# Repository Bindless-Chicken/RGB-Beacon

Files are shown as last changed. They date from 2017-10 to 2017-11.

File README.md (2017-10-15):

<h1 align=center>
   
    <br>
    RGB Beacon
    <br>
</h1>

The RGB Beacon is a small hackable RGB LED based on the ATTiny13a. In addition to a undeniably funky LED, the beacon also integrate a tactile switch and a potentiometer for even more goodness.

## Hardware

### Bill of materials

The MCU inside the Beacon is a [ATTiny13a](http://www.atmel.com/Images/doc8126.pdf) clocked at 9.6MHz using the onboard oscillator.

The RGB LED is the common anode [ASMB-MTB1-0A3A2](https://docs.broadcom.com/docs/AV02-4194EN).

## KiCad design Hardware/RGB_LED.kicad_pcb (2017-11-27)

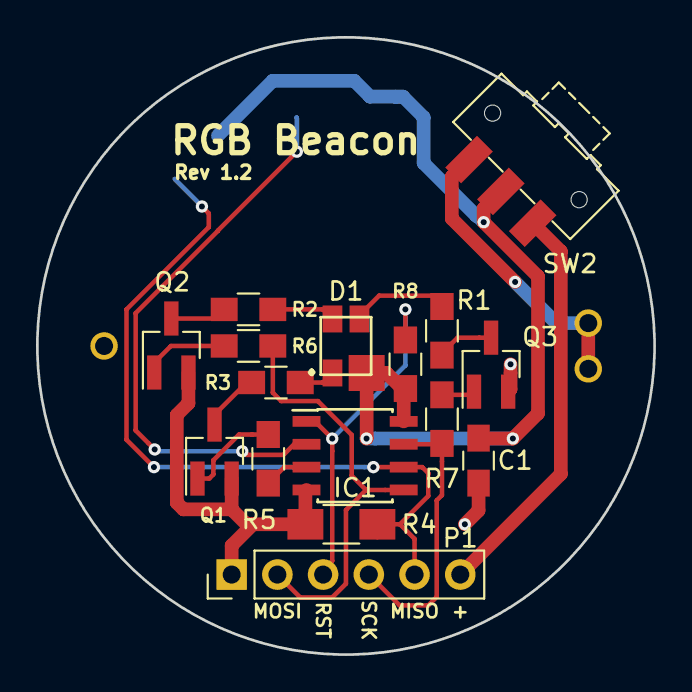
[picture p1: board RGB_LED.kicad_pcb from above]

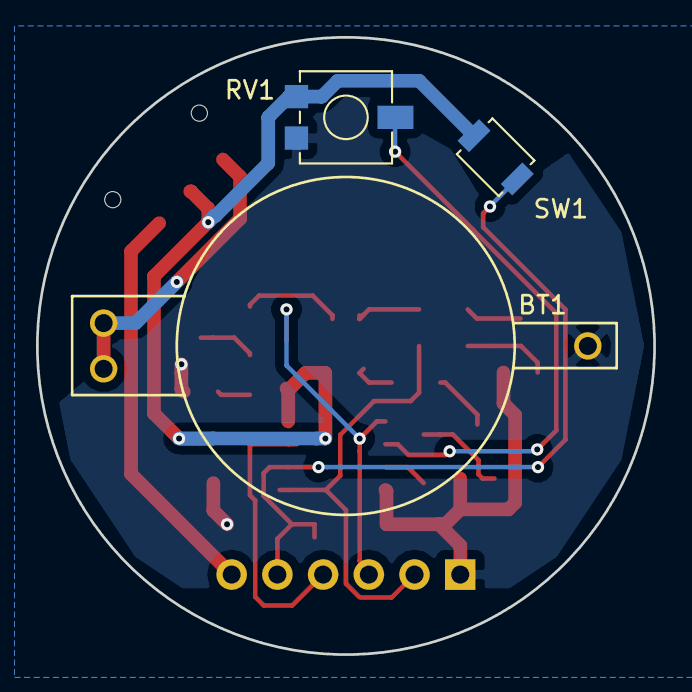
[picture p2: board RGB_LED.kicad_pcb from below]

Board: 2 copper layers, 34.3 x 34.3 mm, 19 parts (3 on the bottom side), 19 nets.

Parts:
BT1: Battery; HU2032-LF
C1: 0.1uF; C_0805_HandSoldering
D1: LED_RABG_2; ASMB-MTB1-0A3A2
IC1: ATTINY13A-SS; SOIC-8_3.9x4.9mm_Pitch1.27mm
P1: CONN_01X06; Socket_Strip_Straight_1x06_Pitch2.54mm
Q1, Q2, Q3: MMBT3904; SOT-23_Handsoldering
R1, R2: 8; R_0805_HandSoldering
R3: 36; R_0805_HandSoldering
R4: 10k; R_1206_HandSoldering
R5, R6, R7: 7k2; R_0805_HandSoldering
R8: 10k; R_0805_HandSoldering
RV1: POT; Potentiometer_Trimmer_Vishay_TS53YL
SW1: SW_PUSH; SW_SPST_B3U-1000P
SW2: Switch_SPDT_x2; SW_SPDT_CK-JS102011SAQN

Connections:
+3V3: C1.1, D1.4, IC1.8, R8.1, RV1.3, SW1.1, SW2.2
/Blue: IC1.7, P1.4, R7.1
/Green: IC1.5, P1.2, R6.1
/ICP_PWR: P1.6, SW2.1
/Red: IC1.3, R5.1
/Switch: IC1.6, P1.5, R4.2, SW1.2
/Trim: IC1.2, RV1.2
GND: BT1.2, C1.2, IC1.4, P1.1, Q1.2, Q2.2, Q3.2, R4.1, RV1.1
unnamed: BT1.1, SW2.3
unnamed: D1.1, R3.2
unnamed: D1.2, R2.2
unnamed: D1.3, R1.2
unnamed: IC1.1, P1.3, R8.2
unnamed: Q1.1, R5.2
unnamed: Q1.3, R3.1
unnamed: Q2.1, R6.2
unnamed: Q2.3, R2.1
unnamed: Q3.1, R7.2
unnamed: Q3.3, R1.1

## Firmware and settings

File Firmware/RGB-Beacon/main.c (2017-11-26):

#include <avr/io.h>
#define F_CPU 9600000
#include <util/delay.h>
#include <avr/interrupt.h>
#include "limits.h"

#include "pinout.h"


// #define UINT16_MAX USHRT_MAX

// Counter stating the number of cycle in the PWM
#define MAX_COUNTER 80

volatile uint16_t ButtonPressBuffer = 0;
volatile uint16_t ButtonPressReader = 0;

// Define the colors register
struct EColors {
	uint8_t Red;
	uint8_t Green;
	uint8_t Blue;
} Colors;

void init(void)
{
	// Init pins
	DDRB = 0x00;
	DDRB = _BV(RED) | _BV(GREEN) | _BV(BLUE);

	// Init ADC
	ADMUX |= (1 << MUX0) | (1 << MUX1);
	ADMUX |= (1 << ADLAR);
	ADCSRA |= (1 << ADPS1) | (1 << ADPS0) | (1 << ADEN);

	// Set interupt for timer
	TCCR0B |= _BV(CS00);
	TIMSK0 |= _BV(TOIE0);

	sei();
}

int adc_read (void)
{
	// Start the conversion
	ADCSRA |= (1 << ADSC);

	// Wait for it to finish - blocking
	while (ADCSRA & (1 << ADSC));

	return ADCH;
}

typedef enum E_DisplayMode{
	RAINBOW,
	ERED,
	EGREEN,
	EBLUE,
	LIGHT
}DisplayMode;

void Rainbow( const int adc)
{
	if(Colors.Blue > 0x00 && Colors.Red == MAX_COUNTER && Colors.Green == 0x00) {
		Colors.Blue-=1;
	}
	if(Colors.Blue == MAX_COUNTER && Colors.Red < MAX_COUNTER && Colors.Green == 0x00) {
		Colors.Red+=1;
	}

	//Fade from green to blue
	if(Colors.Green > 0x00 && Colors.Blue == MAX_COUNTER && Colors.Red == 0x00) {
		Colors.Green-=1;
	}
	if(Colors.Green == MAX_COUNTER && Colors.Blue < MAX_COUNTER && Colors.Red == 0x00) {
		Colors.Blue+=1;
	}

	//Fade from red to green
	if(Colors.Red > 0x00 && Colors.Green == MAX_COUNTER && Colors.Blue == 0x00) {
		Colors.Red-=1;
	}
	if(Colors.Red == MAX_COUNTER && Colors.Green < MAX_COUNTER && Colors.Blue == 0x00) {
		Colors.Green+=1;
	}

	uint8_t i;
	for(i=0; i<adc; ++i)
	{
		_delay_ms(1);
	}
}

void Light( const int adc)
{
	Colors.Red = Colors.Blue = MAX_COUNTER;
	Colors.Green = 0;
}

void Red( const int adc)
{
	Colors.Red = MAX_COUNTER;
	Colors.Green = Colors.Blue = 0;
}

void Green( const int adc)
{
	Colors.Green = MAX_COUNTER;
	Colors.Red = Colors.Blue = 0;
}

void Blue( const int adc)
{
	Colors.Blue = MAX_COUNTER;
	Colors.Green = MAX_COUNTER;
	Colors.Red = MAX_COUNTER;
}

int main(void)
{
	init();

	Colors.Red = MAX_COUNTER;
	Colors.Green = 0;
	Colors.Blue = 0;

	DisplayMode currentMode = EGREEN;

	void (*func)(int);
	func = &Green;

    while (1)
    {
		int adc = adc_read();

		if(ButtonPressReader > 6000)
		{
			Colors.Red = MAX_COUNTER;
			Colors.Green = MAX_COUNTER;
			Colors.Blue = 0;

			_delay_ms(2000);

			ButtonPressReader = 0;

			// Increment the mode
			if(currentMode == EBLUE)
			{
				currentMode = RAINBOW;
			}
			else
			{
				currentMode = (DisplayMode)((int)currentMode +1);
			}

			// Change the function based on the mode
			switch(currentMode)
			{
			case RAINBOW:
				Colors.Red = MAX_COUNTER;
				Colors.Green = 0;
				Colors.Blue = 0;
				func = &Rainbow;
			break;
			case ERED:
				func = &Red;
			break;
			case EGREEN:
				func = &Green;
			break;
			case EBLUE:
				func = &Blue;
			break;
			case LIGHT:
				func = &Red;
			break;
			}
		}

		func(adc);
    }
}

volatile uint8_t pwm_counter = 0x00;


ISR(TIM0_OVF_vect)
{
	uint8_t portb_buffer= 0xFF;

	if( Colors.Red <= pwm_counter)
	{
		portb_buffer &= ~(_BV(RED));
	}

	if( Colors.Green <= pwm_counter)
	{
		portb_buffer &= ~(_BV(GREEN));
	}

	if( Colors.Blue <= pwm_counter)
	{
		portb_buffer &= ~(_BV(BLUE));
	}

	pwm_counter+=1;

	if(pwm_counter == MAX_COUNTER)
	{
		pwm_counter = 0;
	}

	if(PINB & _BV(BUTTON))
	{
		if( ButtonPressBuffer < UINT16_MAX)
			ButtonPressBuffer+=1;


		PORTB = 0x00;
	}
	else
	{
		PORTB = portb_buffer;

		if(ButtonPressBuffer > 0)
			ButtonPressReader = ButtonPressBuffer;

		ButtonPressBuffer = 0;
	}
}

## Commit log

2017-10-05 Commit Hardware
    [RGB_LED.kicad_pcb, RGB_LED.sch]
2017-10-08 Add decoupling cap
    Fix #1
    [RGB_LED.kicad_pcb, RGB_LED.sch]
2017-11-26 Switch sources to c
2017-11-27 Board rev 1.2
    + Add 10k resistor to reset
    + Switch and trim moved to back for better ux
    [RGB_LED.kicad_pcb, RGB_LED.sch]
